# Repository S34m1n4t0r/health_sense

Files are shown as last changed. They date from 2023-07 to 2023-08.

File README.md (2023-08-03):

# Health Sense

Health Sense is a repository that houses the design files for a portable sensor module specifically designed to measure the light intensity in the spectrum of the human eye. This module is primarily developed for research purposes to accurately quantify the light exposure experienced by the human eye.

## Table of Contents
- [Introduction](#introduction)
- [Features](#features)
- [Revisions](#Revisions)
- [Sensors Used](#sensors-used)
- [Getting Started](#getting-started)
- [Usage](#usage)
- [Contributing](#contributing)
- [License](#license)

## Introduction

The human eye is highly sensitive to light, and prolonged exposure to certain intensities and spectrums can have various effects on our overall health and well-being. The Health Sense project aims to provide researchers with a reliable and portable tool for measuring light exposure and analyzing its impact on human subjects.

This repository contains the design files and relevant documentation for the Health Sense sensor module. By using this module, researchers can gather accurate data on light exposure, which can be further utilized for scientific studies, understanding circadian rhythms, evaluating the effects of light on sleep patterns, and other related research areas.

## Features

- **Portable Design**: The Health Sense sensor module is designed to be compact and portable, allowing researchers to easily carry and use it in different environments.
- **Light Intensity Measurement**: The module accurately measures the light intensity in the spectrum of the human eye, providing valuable data for research purposes.
- **Customizable Spectral Range**: Researchers can adjust the spectral range of measurement based on their specific requirements, enabling flexibility in studying different light sources.
- **Data Logging**: The module is equipped with data logging capabilities, allowing researchers to record and analyze light exposure data over extended periods of time.
- **User-Friendly Interface**: The sensor module includes a user-friendly interface, making it easy to operate and configure the device for different research settings.

## Revisions
### Prototyping
Breadboard setup created to verify the correct functionallity of all included sensors.
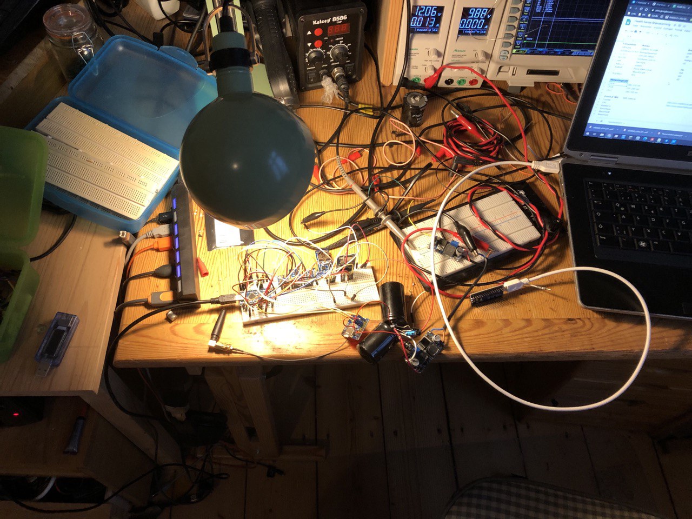
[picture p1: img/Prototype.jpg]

### Revision 1.0
Two prototypes are manufactured and assembled by hand as a final POC. The uC is loaded with the arduino-bootloader.
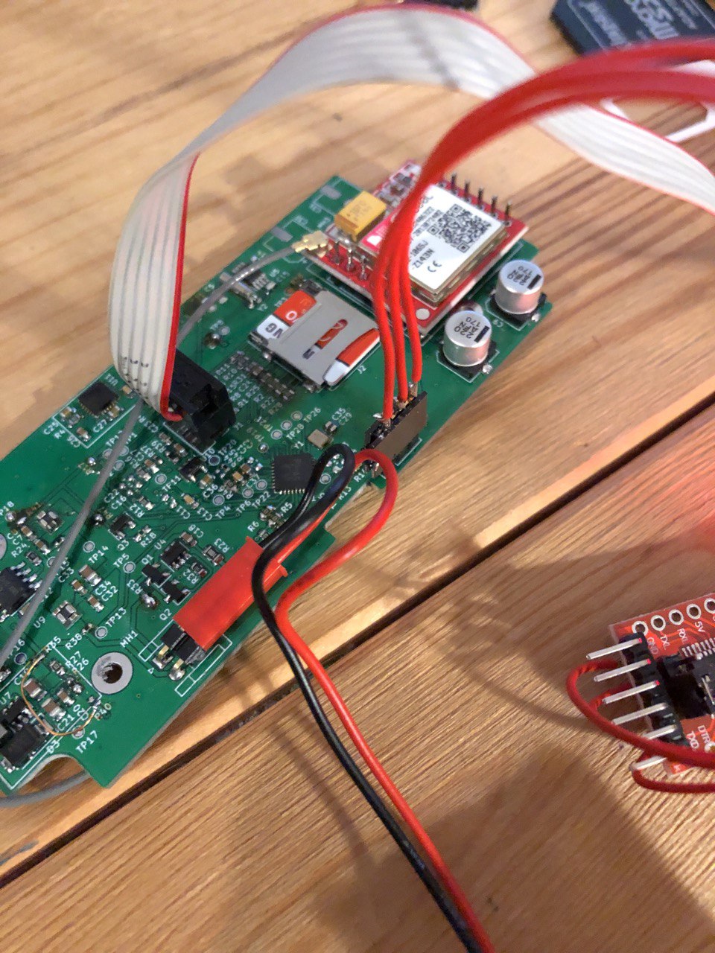
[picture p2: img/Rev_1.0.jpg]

### Revision 1.1
Five prototypes are manufactured and assembled. Enclosure holes are milled with CNC.
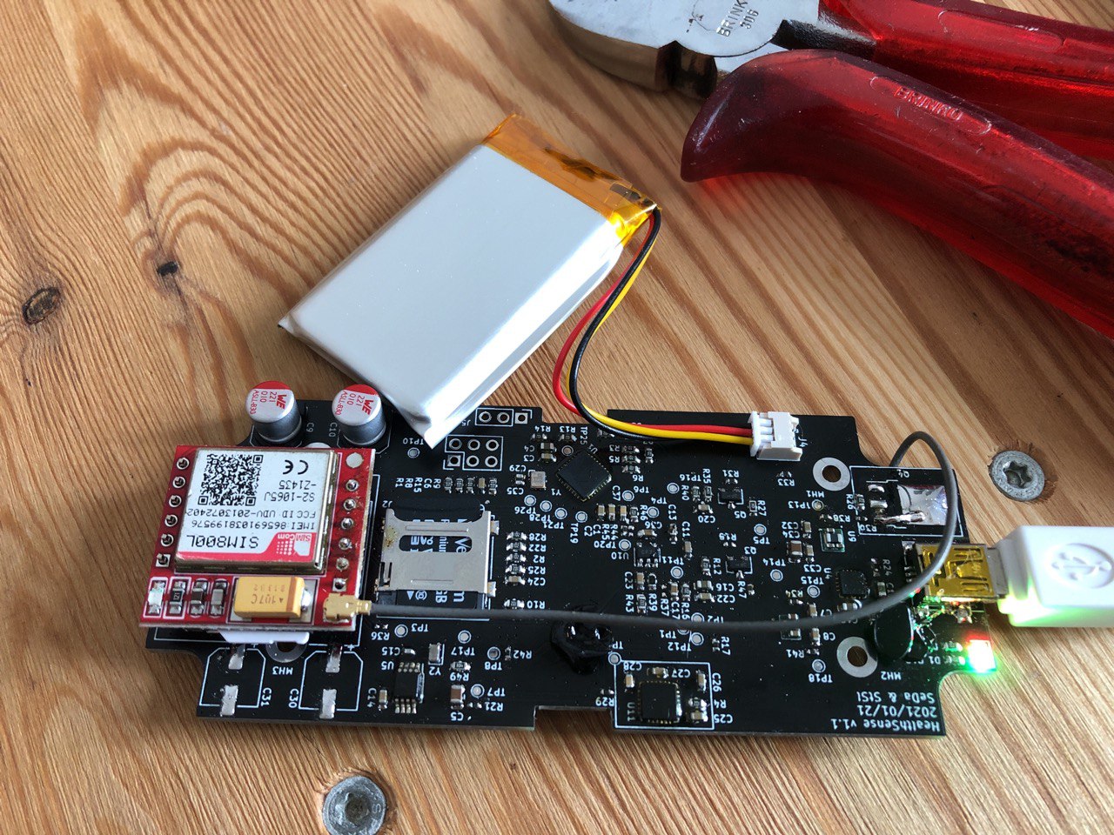
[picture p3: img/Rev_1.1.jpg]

### Known Issues
* Enable transistor for SIM800L not working
* SIM800L as solder-on pcb not optimal. 2/5 modules hat to be replaced.
* Charging current of 100mA could be increased
* Temperature Sensor of lipo not connected to charger IC

## Sensors Used

The Health Sense sensor module incorporates the following sensors:

- Ambient Light Sensor (BH1750): Measures light intensity in the visible spectrum.
- UV-B Sensor (GUVA-S12SD): Measures light intensity in the ultraviolet spectrum.
- Gyroscope Sensor (MPU-6050): Detects and measures orientation and rotation.
- RTC Clock (PCF8563TS): Provides accurate timekeeping functionality for scheduling and data timestamping.
- UMTS Module (SIM800L): Enables communication and data transmission via UMTS cellular network.

The integration of these sensors allows for comprehensive data collection and analysis related to light exposure in the context of research.

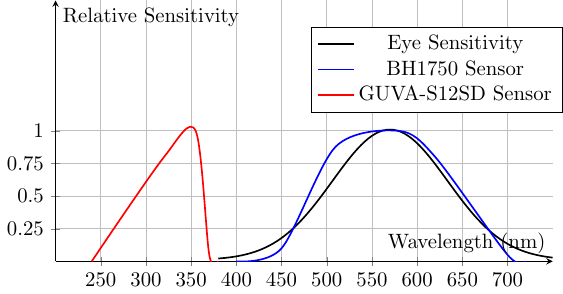
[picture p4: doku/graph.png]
Graph


## Getting Started

To get started with the Health Sense sensor module, follow the steps below:

1. **Hardware Requirements**: Ensure you have the necessary components to assemble the sensor module. Refer to the [BOM](docs/BillOfMaterials_v1.1.csv) and [Schematic](HealthSenseSchematic_v1.1.pdf) for detailed information.

2. **Software Setup**: Install the Arduino IDE, the firmware hexfile can be generated using the arduino ide, choose the Nano Board. Flash the firmware via ISP connector J1.

3. **Calibration**: Before using the sensor module, it is important to calibrate it for accurate light intensity measurements.

4. **Usage**: Once the sensor module is assembled, calibrated, and ready, you can start using it to measure light exposure in your research. See the [Usage](#usage) section for more details.

## Usage

To utilize the Health Sense sensor module for measuring light exposure, follow these steps:

1. Connect the sensor module to a power source and ensure it is properly configured.

2. Position the module in the desired location to measure the light exposure of the human eye.

3. Initiate the measurement process by using the provided software interface or API. The module will start recording light intensity data in the specified spectral range.

4. Allow the module to collect data for the desired duration. The logged data can be stored internally or transmitted to an external device for analysis.

5. Analyze the collected data using appropriate data analysis tools to draw insights and conclusions regarding light exposure in your research.

Refer to the [User Guide](docs/user_guide.md) for detailed instructions on using the Health Sense sensor module effectively.

## Contributing

We welcome contributions from the community to enhance the Health Sense project. 

## License

The Health Sense project is licensed under the [GNU GENERAL PUBLIC LICENSE
](LICENSE). 

## Contact

For any inquiries or feedback regarding the Health Sense project, please contact our team. We appreciate your interest and support!

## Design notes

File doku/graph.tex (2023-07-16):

\documentclass{standalone}
\usepackage{tikz}
\usepackage{pgfplots}
\pgfplotsset{compat=1.16}

\begin{document}
\begin{tikzpicture}
\begin{axis}[
    xlabel={Wavelength (nm)},
    ylabel={Relative Sensitivity},
    ylabel style={rotate=-90},
    ymin=0,
    ymax=2,
    xmin=200,
    xmax=750,
    xtick={250, 300,350, 400, 450, 500, 550, 600, 650, 700},
    xticklabels={250, 300,350, 400, 450, 500, 550, 600, 650, 700},
    ytick={0, 0.25, 0.5, 0.75, 1},
    yticklabels={0, 0.25, 0.5, 0.75, 1},
    grid=both,
    axis lines=middle,
    width=10cm,
    height=6cm,
    legend style={at={(1.02,0.9)}, anchor=north east},
]
\addplot[black, thick, domain=380:780, samples=100] {0.01+exp(-((x-570)/90)^2)};
\addplot[blue, thick, smooth] coordinates {
    (400, 0)
    (450, 0.1)
    (510, 0.88)
    (580, 1)
    (620, 0.8)
    (700, 0.05)
    (720, 0)
};
\addplot[red, thick, smooth] coordinates {
    (240, 0)
    (320, 0.8)
    (355, 1)
    (370, 0.05)
    (380, 0)
};

\legend{Eye Sensitivity, BH1750 Sensor, GUVA-S12SD Sensor}
\end{axis}
\end{tikzpicture}
\end{document}

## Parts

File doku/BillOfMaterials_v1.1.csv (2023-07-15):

Reference | Quantity | Value | Footprint | Datasheet | DigiKey | PartNumber
C1 C2 C3 C20 C14 C24 C26 C25 C27 C22 C11 C23 C36 C7 C8 C33 C32 | 17 | 100n | Capacitor_SMD:C_0603_1608Metric | ~ |  | CL10B104KB8NNNL
C28 C37 | 2 | 2n2 | Capacitor_SMD:C_0603_1608Metric | ~ | 1276-1110-1-ND | CL10B222KB8NNNC
C29 C35 C15 | 3 | 22p | Capacitor_SMD:C_0402_1005Metric | ~ |  | CC0402JRNPO9BN220
C30 C31 | 2 | n.B. | Capacitor_SMD:CP_Elec_6.3x5.8 | ~ |  | n.B.
C4 C16 C12 C18 | 4 | 10u | Capacitor_SMD:C_0603_1608Metric | ~ | 490-10475-1-ND | CL10B222KB8NNNC
C5 C19 C34 | 3 | 22u | Capacitor_SMD:C_0805_2012Metric | ~ |  | GRM21BR61E226ME44L
C6 C13 C17 | 3 | n.B. | Capacitor_SMD:C_0603_1608Metric | ~ |  | n.B.
C9 C10 | 2 | 865060245006 | Capacitor_SMD:CP_Elec_6.3x5.8 | ~ |  | 865060245006
D1 | 1 | LEDG | Diode_SMD:D_0603_1608Metric | ~ |  | LTST-C190KGKT
D3 D2 | 2 | LEDR | Diode_SMD:D_0603_1608Metric | ~ |  | LTST-C190KRKT
D4 | 1 | GUVA-S12SD | Diode_SMD:D_1210_3225Metric_Pad1.42x2.65mm_HandSolder | https://cdn-shop.adafruit.com/datasheets/1918guva.pdf | 2096-GUVA-S12SDCT-ND | GUVA-S12SD
GSM_Module1 | 1 | n.B. | SIM800L:SIM800L |  | n.B. | n.B.
J1 | 1 | ISP | Connector_PinHeader_2.54mm:PinHeader_2x03_P2.54mm_Vertical | ~ | n.B. | n.B.
J2 | 1 | Micro_SD_Card | Connector_Card:microSD_HC_Wuerth_693072010801 | http://katalog.we-online.de/em/datasheet/693072010801.pdf | 732-3820-1-ND | 693072010801
J3 | 1 | USB_B_Mini | Connector_USB:USB_Mini-B_Lumberg_2486_01_Horizontal | ~ | 151-1206-6-ND | 690-005-299-043
J4 | 1 | Conn_01x02 | Connector_JST:JST_EH_S02B-EH_1x02_P2.50mm_Horizontal | ~ | n.B. | n.B.
J5 | 1 | Conn_01x03 | Connector_PinHeader_2.54mm:PinHeader_1x03_P2.54mm_Vertical | ~ | n.B. | n.B.
MH1 MH2 MH3 MH4 | 4 | MountingHole | MountingHole:MountingHole_2.5mm_Pad | ~ | 145-50M025045P004-ND | n.B.
MK1 | 1 | Housing |  |  | 164-1552C3BK-ND | n.B.
Q4 | 1 | Q_PNP_BCEC | Package_TO_SOT_SMD:TO-252-3_TabPin2 | ~ | MJD117T4GOSCT-ND | MJD117T4G
Q5 Q3 | 2 | BC857 | Package_TO_SOT_SMD:SOT-23 | http://www.fairchildsemi.com/ds/BC/BC856.pdf | BC857BLT3GOSCT-ND | BC857BLT3G
R15 R1 R8 R9 | 4 | 100R | Resistor_SMD:R_0603_1608Metric | ~ |  | RC0603JR-07100RL
R18 | 1 | 47K | Resistor_SMD:R_0402_1005Metric | ~ | 311-47.0KLRCT-ND | RC0402FR-0747KL
R24 | 1 | 6K | Resistor_SMD:R_0603_1608Metric | ~ |  | RMCF0603FT56K0
R3 R5 R14 R13 R7 R23 R6 R2 R22 R25 R28 R4 R11 R10 R26 R12 R16 R46 R19 R20 | 20 | 1K | Resistor_SMD:R_0603_1608Metric | ~ |  | CRGCQ0603J1K0
R31 R21 R42 R29 R30 R17 R45 R47 R34 R41 R38 R33 | 12 | 0R | Resistor_SMD:R_0402_1005Metric | ~ |  | RMCF0402ZT0R00
R35 R27 R49 | 3 | 100K | Resistor_SMD:R_0603_1608Metric | ~ |  | RR0816P-104-D
R36 R37 R44 | 3 | n.B. | Resistor_SMD:R_0402_1005Metric | ~ | n.B. | n.B.
R39 | 1 | 7M15 | Resistor_SMD:R_0603_1608Metric | ~ | 541-7.15MHCT-ND | CRCW06037M15FKEA
R40 | 1 | 220k | Resistor_SMD:R_0603_1608Metric | ~ |  | CRGCQ0603F220K
R43 R32 | 2 | 3K3 | Resistor_SMD:R_0603_1608Metric | ~ | A130094CT-ND | CRGCQ0603J3K3
TP1 TP2 TP6 TP3 TP4 TP28 TP26 TP25 TP21 TP19 TP5 TP17 TP16 TP7 TP8 TP9 TP10 TP11 TP12 TP20 TP13 TP14 TP15 TP18 | 24 | TestPoint | TestPoint:TestPoint_Pad_D1.0mm | ~
U1 | 1 | ATmega328P-MU | Package_DFN_QFN:QFN-32-1EP_5x5mm_P0.5mm_EP3.1x3.1mm | http://ww1.microchip.com/downloads/en/DeviceDoc/ATmega328_P%20AVR%20MCU%20with%20picoPower%20Technology%20Data%20Sheet%2040001984A.pdf | ATMEGA328P-MU-ND | ATMEGA328P-MU
U10 | 1 | MCP6001-OT | Package_TO_SOT_SMD:SOT-23-5 | http://ww1.microchip.com/downloads/en/DeviceDoc/21733j.pdf | MCP6001T-I/OTCT-ND | MCP6001T-I/O
U11 | 1 | MPU-6050 | Sensor_Motion:InvenSense_QFN-24_4x4mm_P0.5mm | https://store.invensense.com/datasheets/invensense/MPU-6050_DataSheet_V3%204.pdf | 1428-1007-1-ND | MPU-6050
U2 | 1 | TPS82740 | KiCad_low_energymodules:uSIP-9pin-2.3x2.9mm |  | 296-46481-1-ND | TPS82740BSIPR
U3 | 1 | BH1750 | SIM800L:WSOF6I |  | BH1750FVICT-ND | BH1750FVI-TR
U4 | 1 | BQ24072RGT | Package_DFN_QFN:VQFN-16-1EP_3x3mm_P0.5mm_EP1.6x1.6mm | http://www.ti.com/lit/ds/symlink/bq24072.pdf
U5 | 1 | PCF8563TS | Package_SO:MSOP-8_3x3mm_P0.65mm | https://assets.nexperia.com/documents/data-sheet/PCF8563.pdf | 568-6651-1-ND | PCF8563TS/5,118
U6 | 1 | n.B. | SIM800L:ML8511 |  |  | ML8511
U9 | 1 | TPS81256 | KiCad_low_energymodules:uSIP-9pin-2.57x2.9mm |  | 296-30558-1-ND | TPS81256SIPR
Y1 | 1 | Crystal | Crystal:Crystal_SMD_Abracon_ABM10-4Pin_2.5x2.0mm | ~ | 535-10923-1-ND | ABM10-16.000MHZ-D30-T3
Y2 | 1 | 32.678k | Crystal:Crystal_SMD_2012-2Pin_2.0x1.2mm | ~ | 535-14513-6-ND | ABS06-127-32.768KHZ-T

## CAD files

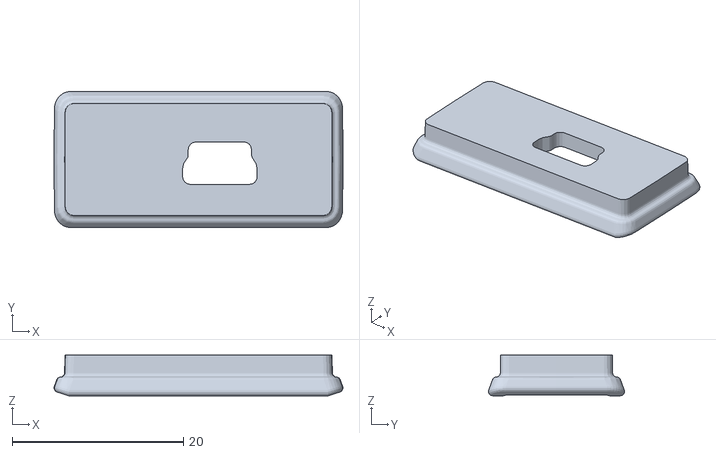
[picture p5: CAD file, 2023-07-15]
mechanical/1552_med_Panel_MiniUSB_v1.stl
33.8 x 15.9 x 4.75

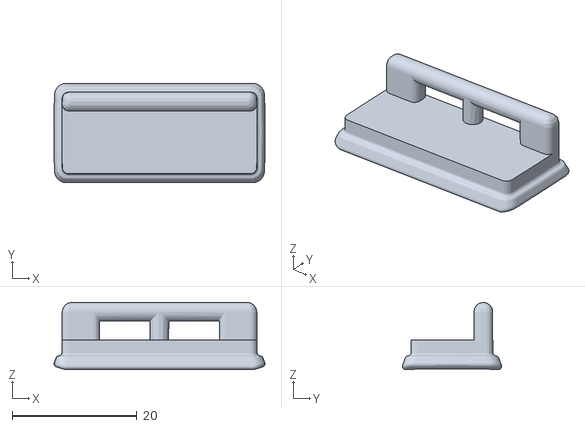
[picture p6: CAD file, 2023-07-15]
mechanical/1552 med Panel_Halter.stl
33.8 x 15.9 x 10.7

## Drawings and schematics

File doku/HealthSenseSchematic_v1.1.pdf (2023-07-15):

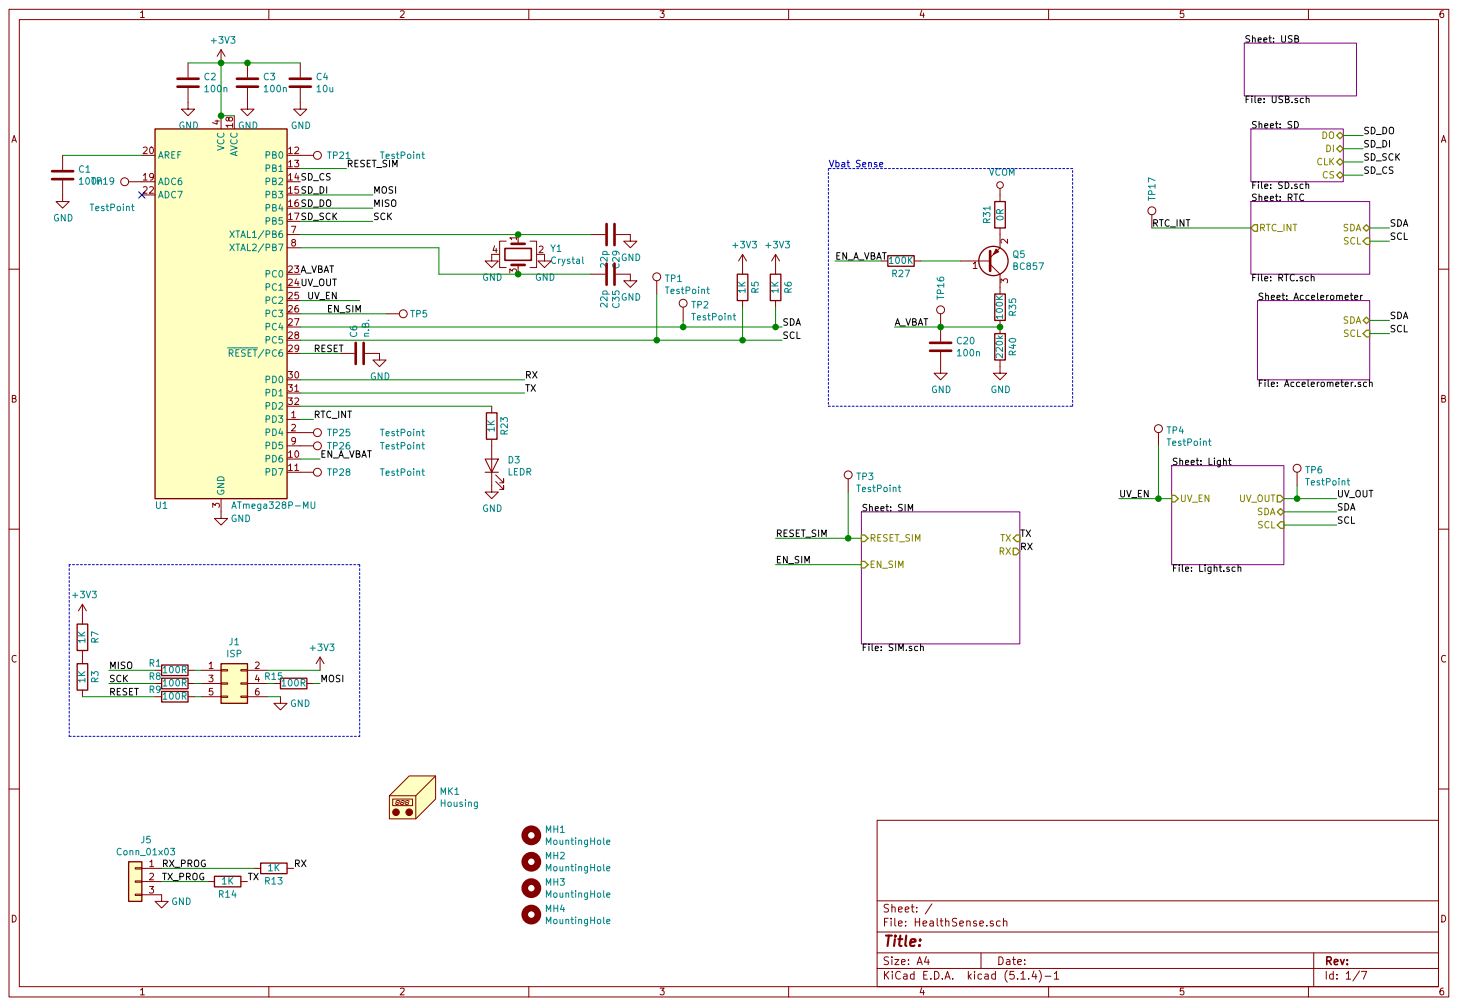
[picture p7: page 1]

File: USB.sch Sheet: SIM
EN_A_VBAT EN_SIM

2 3 Q5BC857 TP19 TestPoint TP21 TestPoint TP25 TestPoint TP26 TestPoint TP28 TestPoint TP4 TestPoint TP3 TestPoint TP6 TestPoint TP2 TestPoint TP1 TestPoint 1KR7 MK1 Housing MH4 MountingHole

Sheet: Accelerometer File: Accelerometer.schSDA

File: Light.sch UV_OUT SDA

Id: 1/7 Title: File: HealthSense.sch Sheet: /

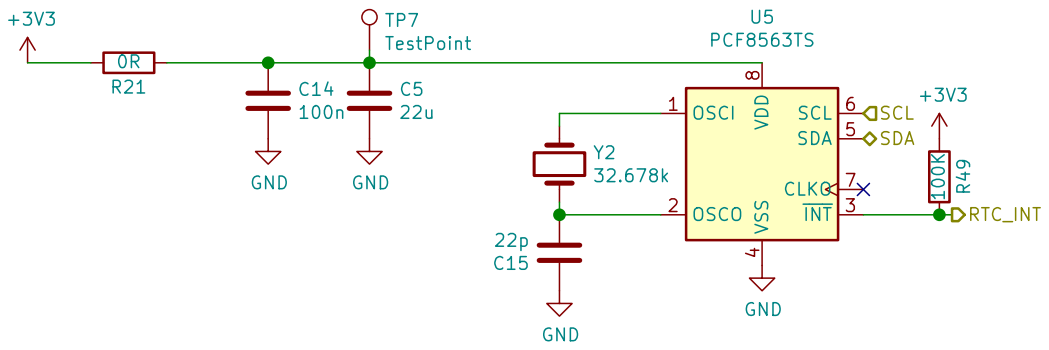
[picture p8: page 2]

4 SDA 5 SCL 6 CLKO 7 VDD

Id: 2/7 Title: File: RTC.sch Sheet: /RTC/

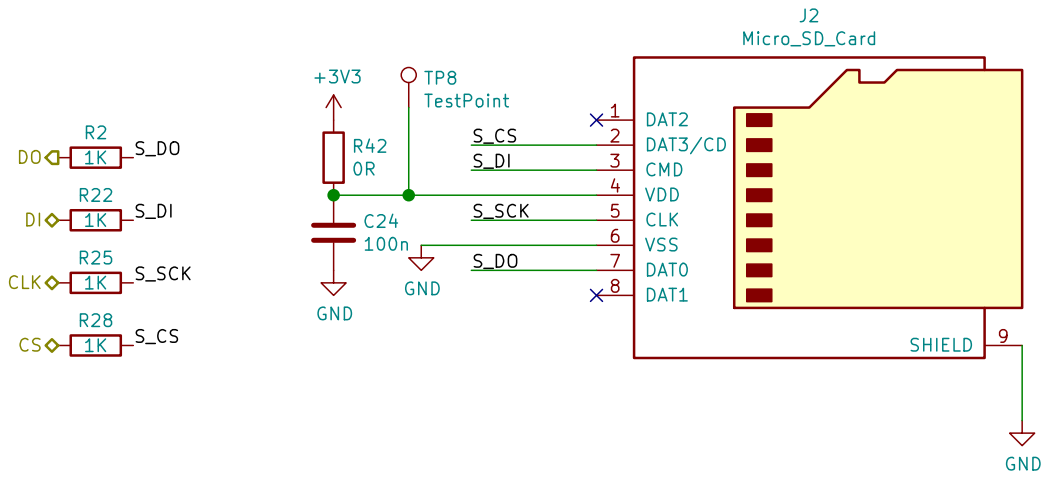
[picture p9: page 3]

Id: 3/7 Title: File: SD.sch Sheet: /SD/

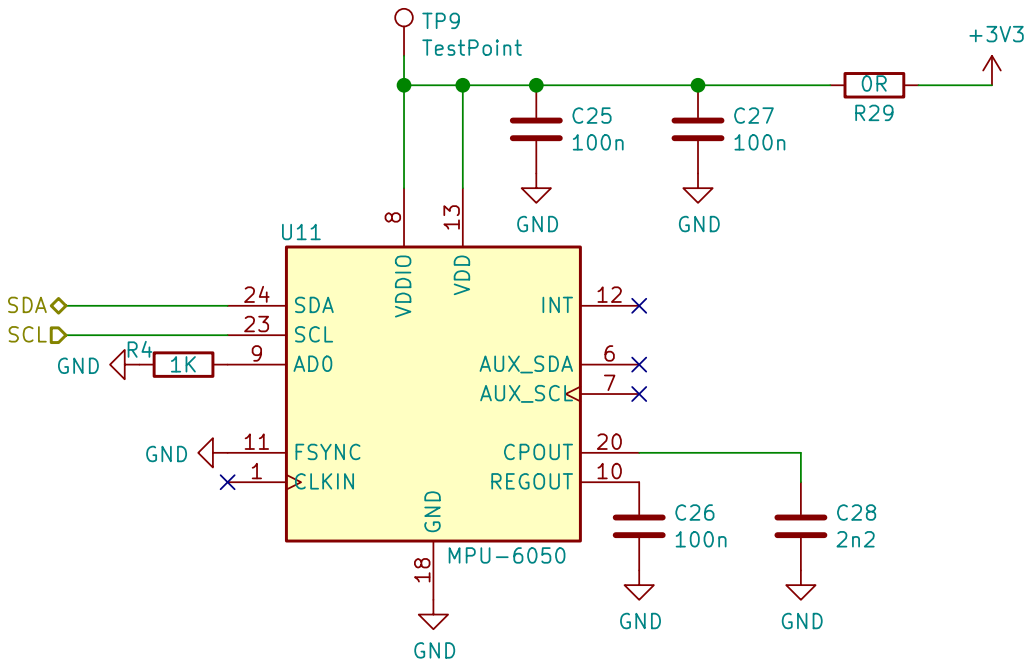
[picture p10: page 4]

Id: 4/7 Title: File: Accelerometer.sch Sheet: /Accelerometer/ GND

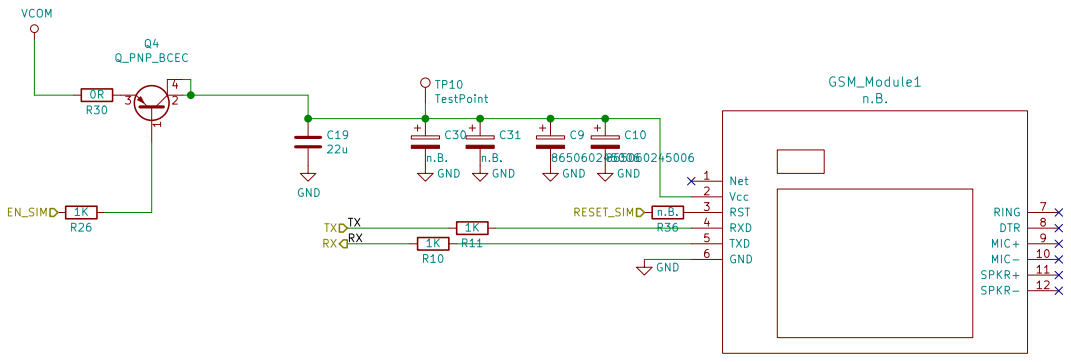
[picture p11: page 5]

Id: 5/7 Title: File: SIM.sch Sheet: /SIM/

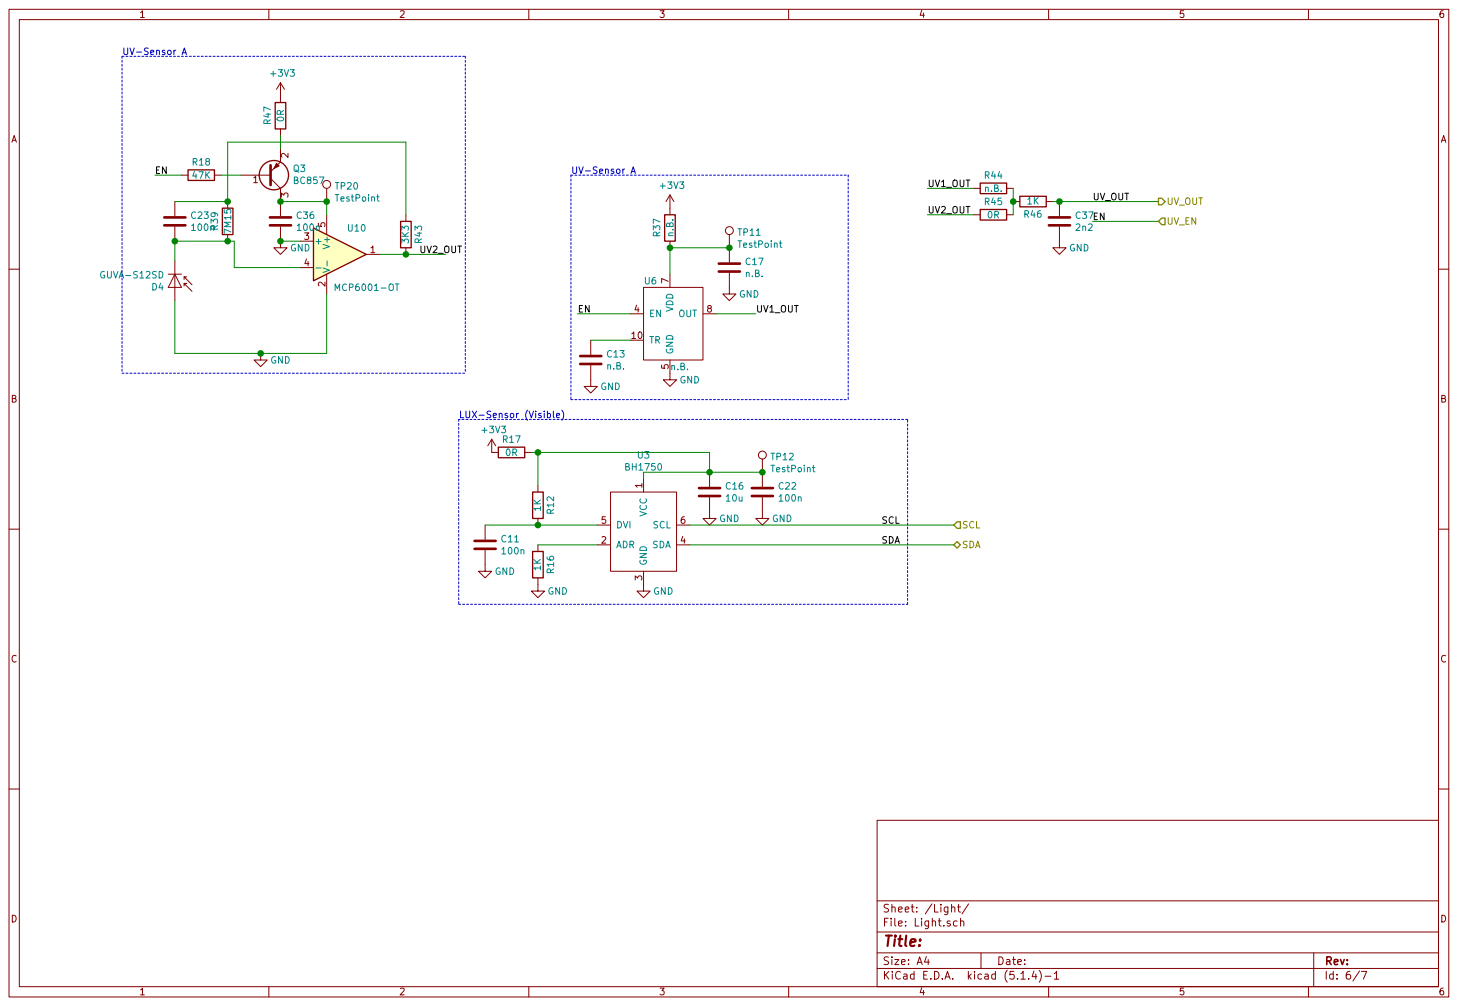
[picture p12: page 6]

3 SDA 4 DVI 5 SCL 6 U3 BH1750 R16 1K GND GND

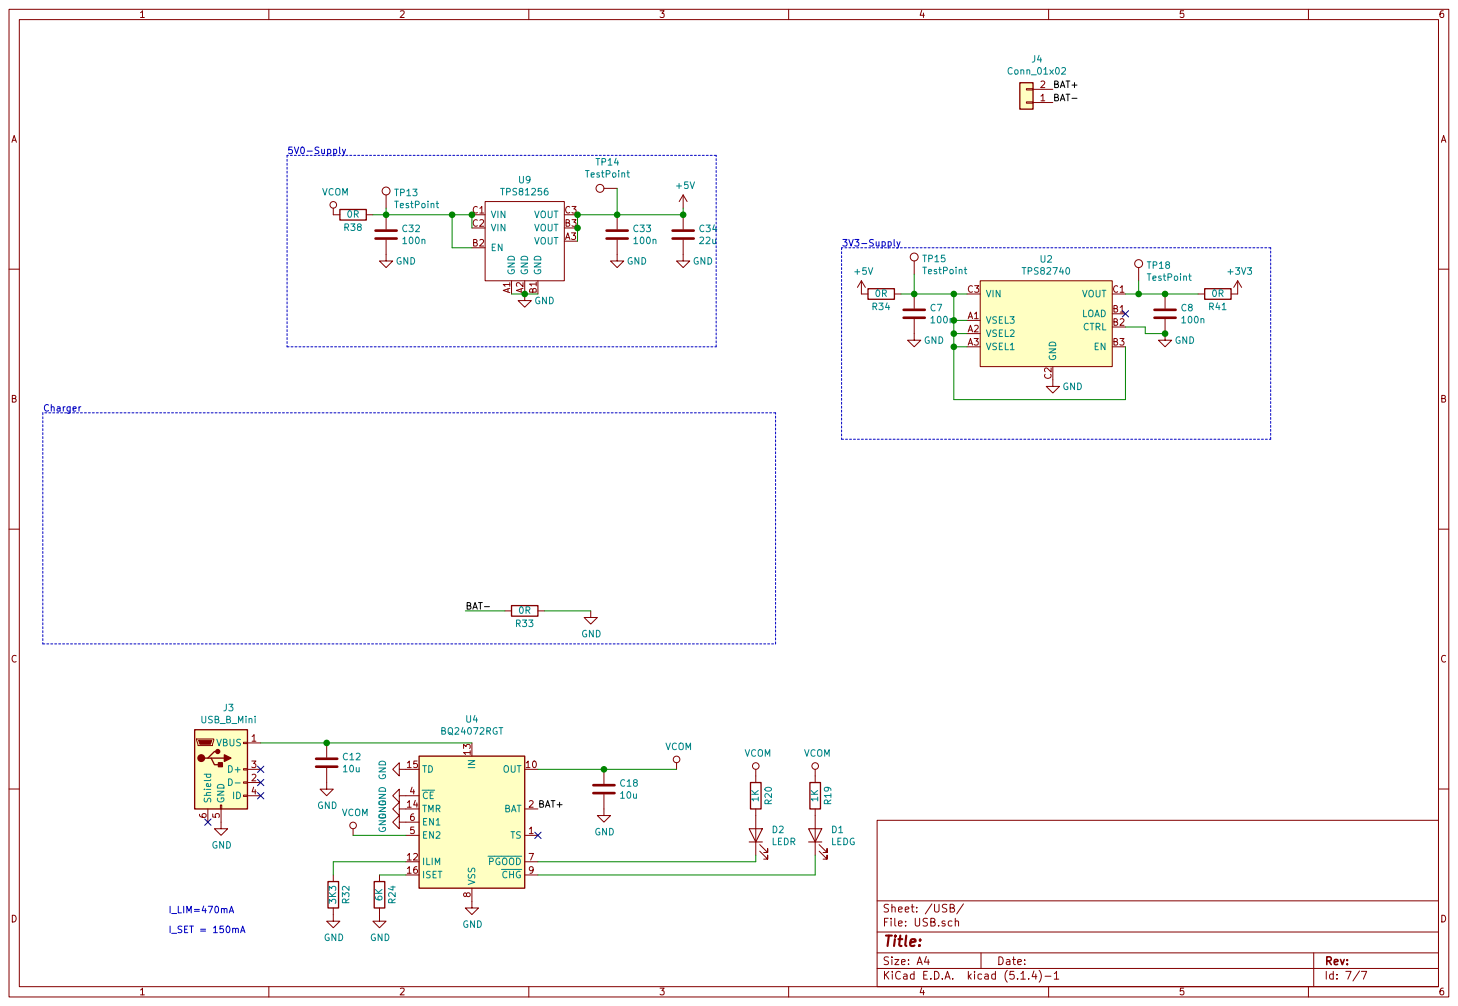
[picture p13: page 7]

Id: 7/7 Title: File: USB.sch Sheet: /USB/

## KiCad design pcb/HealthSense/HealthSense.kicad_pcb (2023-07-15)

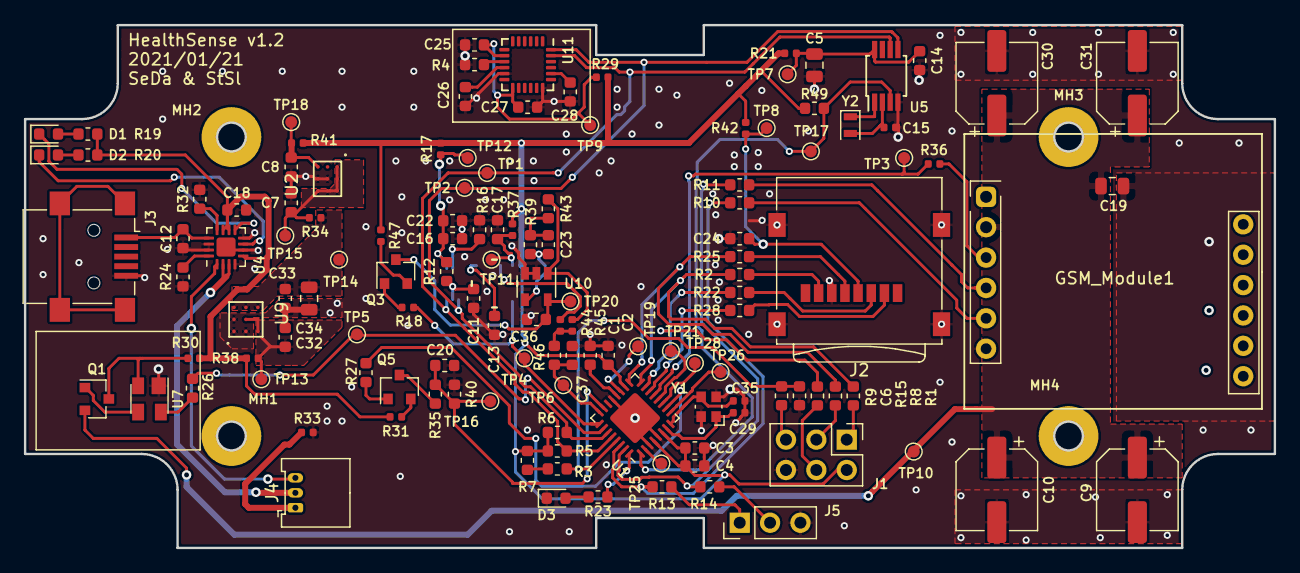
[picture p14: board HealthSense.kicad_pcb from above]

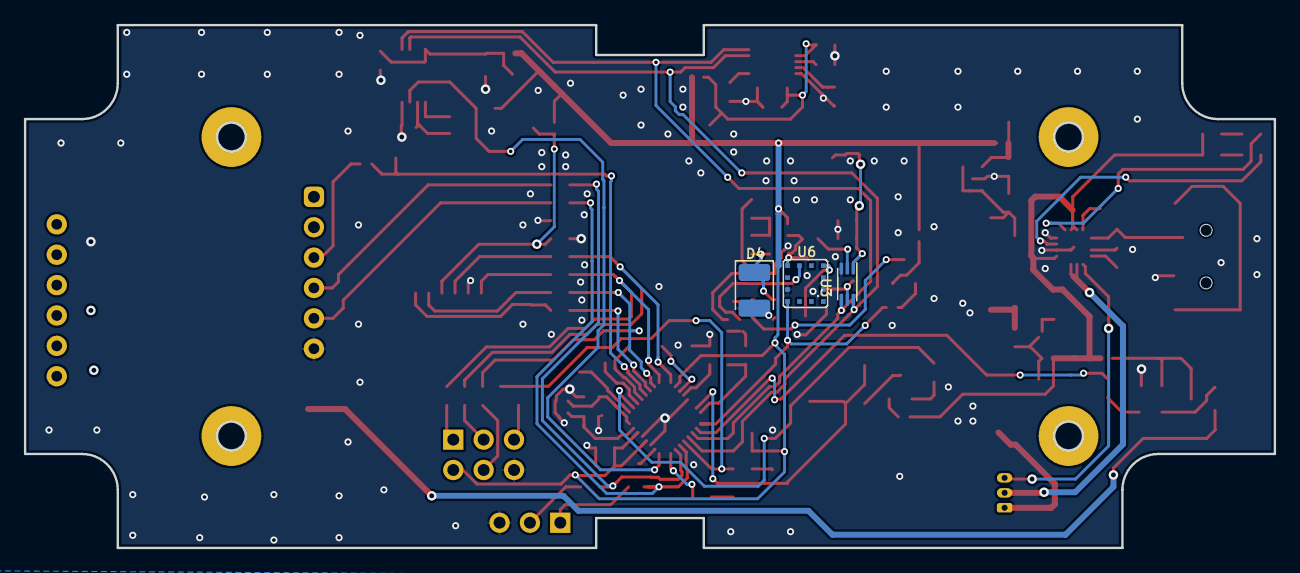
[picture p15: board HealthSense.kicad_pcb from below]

Board: 2 copper layers, 104.5 x 43.7 mm, 137 parts (3 on the bottom side), 85 nets.

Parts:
C1, C2, C3, C7, C8, C11, C14, C20, C22, C23, C24, C25, C26, C27, C32, C33, C36: 100n; C_0603_1608Metric
C4, C12, C16, C18: 10u; C_0603_1608Metric
C5, C19, C34: 22u; C_0805_2012Metric
C6, C13, C17: n.B.; C_0603_1608Metric
C9, C10: 865060245006; CP_Elec_6.3x5.8
C15, C29, C35: 22p; C_0402_1005Metric
C28, C37: 2n2; C_0603_1608Metric
C30, C31: n.B.; CP_Elec_6.3x5.8
D1: LEDG; D_0603_1608Metric
D2, D3: LEDR; D_0603_1608Metric
D4: GUVA-S12SD; D_1210_3225Metric_Pad1.42x2.65mm_HandSolder
GSM_Module1: n.B.; SIM800L
J1: ISP; PinHeader_2x03_P2.54mm_Vertical
J2: Micro_SD_Card; microSD_HC_Wuerth_693072010801
J3: USB_B_Mini; USB_Mini-B_Lumberg_2486_01_Horizontal
J4: Conn_01x03; Molex_PicoBlade_53048-0310_1x03_P1.25mm_Horizontal
J5: Conn_01x03; PinHeader_1x03_P2.54mm_Vertical
MH1, MH2, MH3, MH4: MountingHole; MountingHole_2.5mm_Pad
Q1: Q_NMOS_GSD; SOT-23
Q3, Q5: BC857; SOT-23
R1, R8, R9, R15: 100R; R_0603_1608Metric
R2, R3, R4, R5, R6, R7, R10, R11, R12, R13, R14, R16, R19, R20, R22, R23, R25, R26, R28, R46: 1K; R_0603_1608Metric
R17, R21, R29, R30, R31, R33, R34, R38, R41, R42, R45, R47: 0R; R_0402_1005Metric
R18: 47K; R_0402_1005Metric
R24: 6K; R_0603_1608Metric
R27, R35, R49: 100K; R_0603_1608Metric
R32, R43: 3K3; R_0603_1608Metric
R36, R37, R44: n.B.; R_0402_1005Metric
R39: 7M15; R_0603_1608Metric
R40: 220k; R_0603_1608Metric
TP1, TP2, TP3, TP4, TP5, TP6, TP7, TP8, TP9, TP10, TP11, TP12, TP13, TP14, TP15, TP16, TP17, TP18, TP19, TP20, TP21, TP25, TP26, TP28: TestPoint; TestPoint_Pad_D1.0mm
U1: ATmega328P-MU; QFN-32-1EP_5x5mm_P0.5mm_EP3.1x3.1mm
U2: TPS82740; uSIP-9pin-2.3x2.9mm
U3: BH1750; WSOF6I
U4: BQ24072RGT; VQFN-16-1EP_3x3mm_P0.5mm_EP1.6x1.6mm
U5: PCF8563TS; MSOP-8_3x3mm_P0.65mm
U6: n.B.; ML8511
U7: MIC5018; SOT-143
U9: TPS81256; uSIP-9pin-2.57x2.9mm
U10: MCP6001-OT; SOT-23-5
U11: MPU-6050; InvenSense_QFN-24_4x4mm_P0.5mm
Y1: Crystal; Crystal_SMD_Abracon_ABM10-4Pin_2.5x2.0mm
Y2: 32.678k; Crystal_SMD_2012-2Pin_2.0x1.2mm

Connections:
+3V3: C2.1, C3.1, C4.1, J1.2, R5.2, R6.2, R7.2, R17.2, R21.1, R29.2, R37.1, R41.2, R42.1, R47.1, R49.2, U1.4, U1.6, U1.18
+5V: C33.1, C34.1, R34.1, TP14.1, U9.A3, U9.B3, U9.C3
/A_VBAT: C20.1, R35.1, R40.2, TP16.1, U1.23
/EN_A_VBAT: R27.1, U1.10
/EN_SIM: R26.1, TP5.1, U1.26
/Light/UV1_OUT: R44.2, U6.8
/Light/UV2_OUT: R43.1, R45.2, U10.1
/MISO: R1.1, R2.2, U1.16
/MOSI: R15.2, R22.2, U1.15
/RESET: C6.1, R3.1, R9.1, U1.29
/RESET_SIM: R36.1, TP3.1, U1.13
/RTC_INT: R49.1, TP17.1, U1.1, U5.3
/RX: R10.1, R13.2, U1.30
/RX_PROG: J5.1, R13.1
/SCK: R8.1, R25.2, U1.17
/SCL: R5.1, TP1.1, U1.28, U3.6, U5.6, U11.23
/SD/S_CS: J2.2, R28.1
/SD/S_DI: J2.3, R22.1
/SD/S_DO: J2.7, R2.1
/SD/S_SCK: J2.5, R25.1
/SDA: R6.1, TP2.1, U1.27, U3.4, U5.5, U11.24
/SD_CS: R28.2, U1.14
/TX: R11.1, R14.2, U1.31
/TX_PROG: J5.2, R14.1
/USB/BAT+: J4.2, U4.2, U4.3
/USB/BAT-: J4.1, R33.1
/USB/TS: J4.3, U4.1
/UV_EN: R18.2, TP4.1, U1.25, U6.4
/UV_OUT: C37.1, R46.2, TP6.1, U1.24
GND: C1.2, C2.2, C3.2, C4.2, C5.2, C6.2, C7.2, C8.2, C9.2, C10.2, C11.2, C12.2, C13.2, C14.2, C15.1, C16.2, C17.2, C18.2, C19.2, C20.2, C22.2, C24.2, C25.2, C26.2, C27.2, C28.2, C29.1, C30.2, C31.2, C32.2, C33.2, C34.2, C35.1, C36.2, C37.2, D3.1, D4.2, GSM_Module1.6, J1.6, J2.6, J2.9, J3.5, J5.3, R4.2, R16.1, R24.1, R32.1, R33.2, R40.1, U1.3, U1.5, U1.21, U1.33, U2.B2, U2.C2, U3.3, U4.4, U4.6, U4.8, U4.14, U4.15, U4.17, U5.4, U6.5, U7.1, U9.A1, U9.A2, U9.B1, U10.2, U10.3, U11.11, U11.18, Y1.2, Y1.4
unnamed: C1.1, U1.20
unnamed: C7.1, R34.2, TP15.1, U2.A1, U2.A2, U2.A3, U2.B3, U2.C3
unnamed: C8.1, R41.1, TP18.1, U2.C1
unnamed: C9.1, C10.1, C19.1, C30.1, C31.1, GSM_Module1.2, Q1.2, TP10.1
unnamed: C11.1, R12.1, U3.5
unnamed: C12.1, J3.1, U4.13
unnamed: C13.1, U6.10
unnamed: C5.1, C14.1, R21.2, TP7.1, U5.8
unnamed: C15.2, U5.2, Y2.2
unnamed: C16.1, C22.1, R12.2, R17.1, TP12.1, U3.1
unnamed: C17.1, R37.2, TP11.1, U6.7
unnamed: C23.1, R39.1, R43.2
unnamed: C23.2, D4.1, R39.2, U10.4
unnamed: C24.1, J2.4, R42.2, TP8.1
unnamed: C25.1, C27.1, R29.1, TP9.1, U11.8, U11.13
unnamed: C26.1, U11.10
unnamed: C28.1, U11.20
unnamed: C29.2, U1.7, Y1.1
unnamed: C32.1, R38.2, TP13.1, U9.B2, U9.C1, U9.C2
unnamed: C35.2, U1.8, Y1.3
unnamed: C36.1, Q3.3, TP20.1, U10.5
unnamed: D1.1, U4.9
unnamed: D1.2, R19.1
unnamed: D2.1, U4.7
unnamed: D2.2, R20.1
unnamed: D3.2, R23.1
unnamed: GSM_Module1.3, R36.2
unnamed: GSM_Module1.4, R11.2
unnamed: GSM_Module1.5, R10.2
unnamed: J1.1, R1.2
unnamed: J1.3, R8.2
unnamed: J1.4, R15.1
unnamed: J1.5, R9.2
unnamed: Q1.1, U7.3
unnamed: Q1.3, R30.2, U7.2
unnamed: Q3.1, R18.1
unnamed: Q3.2, R47.2
unnamed: Q5.1, R27.2
unnamed: Q5.2, R31.2
unnamed: Q5.3, R35.2
unnamed: R3.2, R7.1
unnamed: R4.1, U11.9
unnamed: R16.2, U3.2
unnamed: R23.2, U1.32
unnamed: R24.2, U4.16
unnamed: R26.2, U7.4
unnamed: R32.2, U4.12
unnamed: R44.1, R45.1, R46.1
unnamed: TP19.1, U1.19
unnamed: TP21.1, U1.12
unnamed: TP25.1, U1.2
unnamed: TP26.1, U1.9
unnamed: TP28.1, U1.11
unnamed: U5.1, Y2.1
VCOM: C18.1, R19.2, R20.2, R30.1, R31.1, R38.1, U4.5, U4.10, U4.11

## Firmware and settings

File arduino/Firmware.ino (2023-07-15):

/* 
 * This file is part of the HealthSense project (https://gitlab.com/S34m1n4t0r/HealthSense.git).
 * Copyright (c) 2021 Stefan Slooten.
 * 
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
 * You should have received a copy of the GNU General Public License 
 * along with this program. If not, see <http://www.gnu.org/licenses/>.
 */
/* ################################################## */
/* ############### Include Libraries ################ */
/* ################################################## */
#include "Wire.h"
#include "I2Cdev.h"
#include <MPU6050.h>
#include "I2C_BM8563.h"
#include "SD.h"
#include "BH1750.h"
#include "phone_number.h"
/*Define phone_number in phone_number.h*/

/* ################################################## */
/* ############ Destination Phone Number ############ */
/* ################################################## */
const char PHONE_NUMBER_DESTINATION[] = PHONE_NUMBER_DEFINE;

/* ################################################## */
/* ################### Definitions ################## */
/* ################################################## */
#define SDFILE_PIN_CS	10
#define SIM800L_RESET_PIN 9
#define UVSENSOR_PIN_OUT	A1
#define UVSENSOR_PIN_3_3V	A0
#define UVSENSOR_ENABLE_PIN A2
#define MOVEMENT_TIMEOUT_IN_MULTIPLES_OF_30S 720 //6h
#define MOVEMENT_THRESHOLD 2000
#define TIME_START 8 //Uhr
#define TIME_STOP 20 //Uhr
#define LED_PIN 2     //D2
#define SIM_EN 17
#define EN_A_VBAT 6

/* ################################################## */
/* ########## Global object initialization ########## */
/* ################################################## */
MPU6050 mpu6050;
File sdFile;
BH1750 lightMeter;
I2C_BM8563 rtc(I2C_BM8563_DEFAULT_ADDRESS, Wire);

/* ################################################## */
/* ################ type definitions ################ */
/* ################################################## */
typedef struct {
  uint8_t year;
  uint8_t month;
  uint8_t day;
  uint8_t hour;
  uint8_t minute;
  uint8_t second;
} timestamp_t;

typedef struct{
  int16_t gx;
  int16_t gy;
  int16_t gz;  
} movement_t;

/* ################################################## */
/* ############### Function Prototypes ############## */
/* ################################################## */
void SendInitCompleteViaSms(void);
void SendSdCardInitErrorViaSms(void);
void SendSdCardRuntimeErrorViaSms(void);
void SendNoMovementErrorViaSms(void);
void SendWrongDateErrorViaSms(void);
void SetupSms(void);
void TriggerSendSms(void);
void UpdateRtcTimeFromSim800(void);
//void SetSleepModeForSimModule(bool enable);
timestamp_t GetTimestamp();
movement_t GetMovement(void);

void blink_once()
{
  digitalWrite(LED_PIN,HIGH);
  delay(1000);
  digitalWrite(LED_PIN,LOW);
  delay(1000);
  digitalWrite(LED_PIN,HIGH);
}

/* ################################################## */
/* ############# Arduino Setup Routine ############## */
/* ################################################## */
void setup()
{
  // I2C interface init for RTC, GYRO and Lightsensor (BH1750)
  Wire.begin();
  //Setup Debug-Led. Activate during init
  pinMode(LED_PIN, OUTPUT);
  
  //Setup Vbat meas
  pinMode(EN_A_VBAT, INPUT); 
  //digitalWrite(EN_A_VBAT,HIGH);
  //Enable Sim800 Module
  pinMode(SIM_EN, OUTPUT); 
  digitalWrite(SIM_EN,LOW);
  
  delay(100);
  // Lightsensor (visible) init
  lightMeter.begin(BH1750::ONE_TIME_HIGH_RES_MODE);
  blink_once();
  // rtc init
  rtc.begin();
  blink_once();
  // Gyro
  mpu6050.initialize();
  blink_once();
  // Lightsensor UV enable
  pinMode(UVSENSOR_ENABLE_PIN, OUTPUT); 
  digitalWrite(UVSENSOR_ENABLE_PIN,LOW);
  // SIM800L UMTS module enable
  pinMode(SIM800L_RESET_PIN, OUTPUT); 
  digitalWrite(SIM800L_RESET_PIN,HIGH);
  
  // SIM800L init
  Serial.begin(9600);
  // sd card init and error message if failed
  pinMode(SDFILE_PIN_CS, OUTPUT);  
  
  if (SD.begin())
  {
    blink_once();
    UpdateRtcTimeFromSim800();
    blink_once();
    SendInitCompleteViaSms();
  }
  else
  {
    SendSdCardInitErrorViaSms();
    while (true)
    {
      /* safe state */
      delay(1000);
      digitalWrite(LED_PIN,LOW);
      delay(1000);
      digitalWrite(LED_PIN,HIGH);
    }
  }
  digitalWrite(LED_PIN,LOW);
  /*LED indicates setup */

  //SetSleepModeForSimModule(true);
}

/* ################################################## */
/* ############### Arduino Main Loop ################ */
/* ################################################## */
uint16_t movementTimeout = MOVEMENT_TIMEOUT_IN_MULTIPLES_OF_30S;
void loop()
{
  timestamp_t timestamp = GetTimestamp();
  movement_t movement = GetMovement();
  sdFile = SD.open("protocol.txt", FILE_WRITE);
  if (sdFile)
  {
    digitalWrite(LED_PIN,HIGH);
    sdFile.print(String(timestamp.year));
    sdFile.print(",");
    sdFile.print(String(timestamp.month));
    sdFile.print(",");
    sdFile.print(String(timestamp.day));
    sdFile.print(",");
    sdFile.print(String(timestamp.hour));
    sdFile.print(",");
    sdFile.print(String(timestamp.minute));
    sdFile.print(",");
    sdFile.print(String(timestamp.second));
    sdFile.print(",");
    sdFile.print(String((uint16_t)analogRead(A1)));//uv
    sdFile.print(",");
    sdFile.print(String((uint16_t)lightMeter.readLightLevel(true)));//lux 
    sdFile.print(",");
    sdFile.print(String(movement.gx));
    sdFile.print(",");
    sdFile.print(String(movement.gy));
    sdFile.print(",");
    sdFile.print(String(movement.gz));
    //digitalWrite(EN_A_VBAT,LOW);
    sdFile.print(",");
    sdFile.print(String((uint16_t)analogRead(A0)));//supply
    //digitalWrite(EN_A_VBAT,HIGH);
    sdFile.print("\r\n");
    sdFile.close();
    digitalWrite(LED_PIN,LOW);
  }
  else
  {
    //SetSleepModeForSimModule(false);
    SendSdCardRuntimeErrorViaSms();
    //SetSleepModeForSimModule(true);
  }

  // reset movement counter in night time
  if((timestamp.hour < TIME_START) || (timestamp.hour > TIME_STOP))
  {
    movementTimeout = MOVEMENT_TIMEOUT_IN_MULTIPLES_OF_30S;
  }

  if((abs(movement.gx) + abs(movement.gy) + abs(movement.gz)) < MOVEMENT_THRESHOLD)
  {
    if(0 != movementTimeout)
    {
      movementTimeout--;
    }
    else
    {
      SendNoMovementErrorViaSms();
      movementTimeout = MOVEMENT_TIMEOUT_IN_MULTIPLES_OF_30S;
    }
  }
  else
  {
    movementTimeout = MOVEMENT_TIMEOUT_IN_MULTIPLES_OF_30S;
  }
    
  delay(30000);
}

/* ################################################## */
/* ########### Application Code Functions ########### */
/* ################################################## */
/** 
 * @brief: Sends a SMS to indicate, that initialization has been successfully completed
 * @param: void
 * @return: void
 */
void SendInitCompleteViaSms(void)
{
  SetupSms();
  Serial.print("Setup Complete. Logger is up and running :)");
  TriggerSendSms();
}

/** 
 * @brief: Sends a SMS to indicate, that SD-Card initialization failed
 * @param: void
 * @return: void
 */
void SendSdCardInitErrorViaSms(void)
{
  SetupSms();
  Serial.print("SD-Card Setup Failed. Please insert correctly formatteed SD-Card.");
  TriggerSendSms();
}

/** 
 * @brief: Sends a SMS to indicate, that the SD-Card has been corrupted during runtime
 * @param: void
 * @return: void
 */
void SendSdCardRuntimeErrorViaSms(void)
{
  SetupSms();
  Serial.print("SD-Card Corrupted. Please reformat SD-Card.");
  TriggerSendSms();
}

void FlushSerialBuffer(void)
{
  while(Serial.available() > 0)
  {
    (void)Serial.read();
  }
}

/** 
 * @brief: Sends a SMS to indicate, that no movement has been detected for more than 12h
 * @param: void
 * @return: void
 */
void SendNoMovementErrorViaSms(void)
{
  SetupSms();
  Serial.print("No movement for more than 6h detected.");
  TriggerSendSms();
}

/** 
 * @brief: Sends a SMS to indicate, that date was wrint during init
 * @param: void
 * @return: void
 */
void SendWrongDateErrorViaSms(void)
{
  SetupSms();
  Serial.print("Date could not be acquired.");
  TriggerSendSms();
}

/** 
 * @brief: Sets up the SIM800L module for SMS transmission 
 * @param: void
 * @return: void
 */
void SetupSms(void)
{
  SetSleepModeForSimModule(false);
  Serial.println("AT"); //Once the handshake test is successful, it will back to OK
  delay(1000);
  FlushSerialBuffer();
  Serial.println("ATI"); //Get the module name and revision
  delay(1000);
  FlushSerialBuffer();
  Serial.println("AT+CSQ"); //Signal quality test, value range is 0-31 , 31 is the best
  delay(1000);
  FlushSerialBuffer();
  Serial.println("AT+CCID"); //Read SIM information to confirm whether the SIM is plugged
  delay(1000);
  FlushSerialBuffer();
  Serial.println("AT+CREG=1");
  delay(1000);
  FlushSerialBuffer();
  Serial.println("AT+CREG?"); //Check whether it has registered in the network
  delay(1000);
  FlushSerialBuffer();
  Serial.println("AT+CMGF=1"); // Configuring TEXT mode
  delay(1000);
  FlushSerialBuffer();
  Serial.println("AT+CMGS=\""+String(PHONE_NUMBER_DESTINATION)+"\"");
  delay(1000);
  FlushSerialBuffer();
}

/** 
 * @brief: Triggers the sending of a previously prepared SMS
 * @param: void
 * @return: void
 */
void TriggerSendSms(void)
{
  delay(1000);
  FlushSerialBuffer();
  Serial.write(26);
  Serial.print("AT+CSIM?");
  delay(1000);
  FlushSerialBuffer();

  SetSleepModeForSimModule(true);

}

void UpdateRtcTimeFromSim800(void)
{
  bool isSet = false;
  char uartBuffer[160] = {0}; 
  uint8_t i;
  I2C_BM8563_DateTypeDef dateStruct;
  I2C_BM8563_TimeTypeDef timeStruct;
  uint8_t timeout = 20;

  SetSleepModeForSimModule(false);
  while(!isSet)
  {
    delay(2000);
    FlushSerialBuffer();
    // Check if Time Sync is activated
    Serial.println("AT+CLTS?");
    delay(10000);
    i = 0;
    while(Serial.available() > 0)
    {
      uartBuffer[i] = Serial.read();
      i++;
    }
    for(uint8_t w = 0; w < i ; w++)
    {
      if(uartBuffer[w] == ':')
      {
        isSet = uartBuffer[w + 2] == '1';
      }
    }
    delay(1000);
    timeout--;
    if (timeout == 0)
      isSet=1;
    if(!isSet)
    {
      //Serial.println("AT+CLTS=1");
      Serial.println("AT+CLTS=1;&W");
      delay(1000);
      FlushSerialBuffer();
      Serial.println("AT+CFUN=1,1");
      delay(4000);
      FlushSerialBuffer();
    }
  }

  delay(10000);
  FlushSerialBuffer();
  Serial.println("AT+CTZU=1");
  delay(10000);
  FlushSerialBuffer();
  Serial.println("AT+CREG=1");
  delay(10000);
  FlushSerialBuffer();
  Serial.println("AT+CCLK?");
  delay(10000);
  i = 0;
  while(Serial.available() > 0)
  {
    uartBuffer[i] = Serial.read();
    i++;
  }
  uint8_t w = 0;
  for(w = 0; w < i ; w++)
  {
    if(uartBuffer[w] == '"')
    {
      dateStruct.year = (10 * (uartBuffer[w+1] - 48)) + (uartBuffer[w+2] - 48) + 1900;
      dateStruct.month =  (10 * (uartBuffer[w+4] - 48)) + (uartBuffer[w+5] - 48);
      dateStruct.date =  (10 * (uartBuffer[w+7] - 48)) + (uartBuffer[w+8] - 48);
      timeStruct.hours =  (10 * (uartBuffer[w+10] - 48)) + (uartBuffer[w+11] - 48);
      timeStruct.minutes =  (10 * (uartBuffer[w+13] - 48)) + (uartBuffer[w+14] - 48);
      timeStruct.seconds =  (10 * (uartBuffer[w+16] - 48)) + (uartBuffer[w+17] - 48);
      rtc.setDate(&dateStruct);
      rtc.setTime(&timeStruct);
      break;
    }
  }
  if((dateStruct.year < 21) || (dateStruct.month == 0) || (dateStruct.date == 0))
  {
    SendWrongDateErrorViaSms();
  }
}

/** 
 * @brief: Reads the current time from the BM8563 RTC
 * @param: void
 * @return: timestamp_t   timestamp structure
 */
timestamp_t GetTimestamp()
{
  I2C_BM8563_DateTypeDef dateStruct;
  I2C_BM8563_TimeTypeDef timeStruct;
  rtc.getDate(&dateStruct);
  rtc.getTime(&timeStruct);
  timestamp_t loc_Timestamp;
  loc_Timestamp.year = dateStruct.year % 100;
  loc_Timestamp.month = dateStruct.month;
  loc_Timestamp.day = dateStruct.date;
  loc_Timestamp.hour = timeStruct.hours;
  loc_Timestamp.minute = timeStruct.minutes;
  loc_Timestamp.second = timeStruct.seconds;
  return loc_Timestamp;
}

/** 
 * @brief: Reads the current movement from the MPU6050 Gyro
 * @param: void
 * @return: movement_t   movement structure
 */
movement_t GetMovement(void)
{
  movement_t movement;
  int16_t dump;
  mpu6050.getMotion6(&dump, &dump, &dump, &(movement.gx), &(movement.gy), &(movement.gz));
  return movement;
}

void SetSleepModeForSimModule(bool enable)
{
  if (enable)
  {
    Serial.println("AT+CSCLK=2");
    delay(1000);
     FlushSerialBuffer();
  }else
  {
    Serial.println("AT+CSCLK=0");
     delay(1000);
     FlushSerialBuffer();
    delay(10000);
  }
}

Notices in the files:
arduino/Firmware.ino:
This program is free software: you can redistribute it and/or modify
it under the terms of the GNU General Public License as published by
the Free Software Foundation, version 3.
